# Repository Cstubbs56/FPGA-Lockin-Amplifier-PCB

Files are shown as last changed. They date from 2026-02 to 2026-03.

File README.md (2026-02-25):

# FPGA-Lockin-Amplifier-PCB
## Purpose
This PCB acts as both DAQ and a lock in amplifier for the Waterloo Rocketry 2026 fiber optic gyroscope payload. To accomplish this, it 
- Biases the fibre optic loop by outputting a sinusoid to a piezoelectric crystal via a DAC with fibre optic wrapped around the PZT.
- Reads the output of the interferometer through a photodiode into a transimpedance amplifier and ADC.
- Calculates I and Q components then exports to an SD card going through the microcontroller.

## Power Electronics
The PCB needs 24V, 5V, 3.3V, 2.5V, and 1.2V. The 24V is used for biasing the piezoelectric crystal, and goes through a 0-20V output 16 bit DAC. 5V and 3.3V are used for the analog and digital circuitry, while the 2.5V and 1.2V are solely for powering the FPGA.

## Analog Electronics
As mentioned, there is an ADC reading a transimpedance amplifier. The transimpedance amplifier was sized based on an estimated maxium output power from the interferometer of 20mW into a photodiode with an approximate response of 0.55A/W. The other side is the aforementioned DAC, which is setup to output 0-20V with a sinusoid from the FPGA.

## Logging
The FPGA being used does nt have enough extra space in the fabric to interact with a filesystem and therefore the FPGA sends results to the microcontroller to be held in RAM before outputting to the SD card. There is a piece of flash memory connected to the FPGA, but this is used for configuration.

## FPGA
Since the FPGA's non-volatile configuration memory can only be written to once, the FPGA is used with volatile configuration. This means it must configure itself each time it powers on. It uses SPI for configuration, which is hooked up to both a flash ROM and a SPI header that can be used for programming the memory from a computer.  

## Laser
The laser on the PCB is a 200mW optical power infrared laser. It draws typically around 300mA in operation.

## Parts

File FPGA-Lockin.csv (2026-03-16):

Id | Designator | Footprint | Quantity | Designation | Supplier and ref
1 | U3,U6 | SOT-563 | 2 | TLV62568ADRL
2 | R27,R26,R24 | R_0805_2012Metric_Pad1.20x1.40mm_HandSolder | 3 | 100kR
3 | L3,L2 | L_1206_3216Metric_Pad1.22x1.90mm_HandSolder | 2 | 1uH
4 | C5,C11 | C_0805_2012Metric_Pad1.18x1.45mm_HandSolder | 2 | 22uF
5 | C4,C34,C9 | C_0805_2012Metric_Pad1.18x1.45mm_HandSolder | 3 | 4.7uF
6 | C29,C12,C23,C35,C41 | C_0805_2012Metric_Pad1.18x1.45mm_HandSolder | 5 | 2.2uF
7 | C18,C17,C28,C36,C45,C40,C15,C42,C8,C38,C19,C24,C39,C37,C25 | C_0805_2012Metric_Pad1.18x1.45mm_HandSolder | 15 | 0.1uF
8 | TP11 | TestPoint_Pad_D1.0mm | 1 | SS1_an
9 | D5 | TO-5-3 | 1 | D_Photo
10 | TP7 | TestPoint_Pad_D1.0mm | 1 | MISO_an
11 | C31,C30 | C_0805_2012Metric_Pad1.18x1.45mm_HandSolder | 2 | 10pF
12 | R14,R13,R25,R22,R17,R16,R15,R20,R18,R21,R19 | R_0805_2012Metric_Pad1.20x1.40mm_HandSolder | 11 | 10kR
13 | R23 | R_0805_2012Metric_Pad1.20x1.40mm_HandSolder | 1 | 453kR
14 | TP4 | TestPoint_Pad_1.5x1.5mm | 1 | 2V5
15 | C21 | CP_EIA-7132-20_AVX-U_HandSolder | 1 | 120uF
16 | TP6 | TestPoint_Pad_1.5x1.5mm | 1 | 24V
17 | TP9,TP8 | TestPoint_Pad_D1.0mm | 2 | MOSI_an
18 | U7 | LQFP-64_10x10mm_P0.5mm | 1 | STM32F405RGTx
19 | J6 | PinSocket_2x07_P1.27mm_Vertical_SMD | 1 | Conn_02x07_Odd_Even
20 | U11 | SOIC-8_3.9x4.9mm_P1.27mm | 1 | MCP1501-30xSN
21 | C26 | C_0805_2012Metric_Pad1.18x1.45mm_HandSolder | 1 | 10 nF
22 | R9 | R_0805_2012Metric_Pad1.20x1.40mm_HandSolder | 1 | 1MR
23 | U4 | SOT-23-5 | 1 | SPX3819M5-L-2-5
24 | U8 | SOT-23-5_HandSoldering | 1 | SPX3819M5-L-3-3
25 | R10 | R_0805_2012Metric_Pad1.20x1.40mm_HandSolder | 1 | 249kR
26 | D1 | DIO_RB051MM_ROM | 1 | D_Schottky
27 | C7 | C_1210_3225Metric_Pad1.33x2.70mm_HandSolder | 1 | 180uF
28 | C27 | C_1210_3225Metric_Pad1.33x2.70mm_HandSolder | 1 | 0.1uF
29 | C43,C10,C22,C1,C3,C14 | C_0805_2012Metric_Pad1.18x1.45mm_HandSolder | 6 | 1uF
30 | TP5 | TestPoint_Pad_1.5x1.5mm | 1 | 1V2
31 | Y1 | Crystal_SMD_Abracon_ABM8G-4Pin_3.2x2.5mm | 1 | ABM8G
32 | U13 | RU-16_ADI | 1 | AD5761RBRUZ-RL7
33 | U12 | TSSOP20_ST_MCH | 1 | MCP3561R-E/ST
34 | R11 | R_0805_2012Metric_Pad1.20x1.40mm_HandSolder | 1 | 13.3kR
35 | C13 | C_1210_3225Metric_Pad1.33x2.70mm_HandSolder | 1 | 4.7uF
36 | U1 | QFN-48-1EP_7x7mm_P0.5mm_EP5.6x5.6mm | 1 | ICE40UP5K-SG48ITR
37 | TP10 | TestPoint_Pad_D1.0mm | 1 | SS0_an
38 | TP1 | TestPoint_Pad_1.5x1.5mm | 1 | 5v
39 | TP2 | TestPoint_Pad_1.5x1.5mm | 1 | 3V3
40 | U5 | SOT-23-5 | 1 | LMR64010XMF
41 | R7,R8 | R_0805_2012Metric_Pad1.20x1.40mm_HandSolder | 2 | 10R
42 | C2,C20 | C_0805_2012Metric_Pad1.18x1.45mm_HandSolder | 2 | 10nF
43 | J7 | PinSocket_1x02_P2.54mm_Vertical | 1 | Conn_01x02_Pin
44 | U14 | SOT25_DIO | 1 | AP22802AW5-7
45 | TP3 | TestPoint_Pad_1.5x1.5mm | 1 | 3V3A
46 | R4 | R_0805_2012Metric_Pad1.20x1.40mm_HandSolder | 1 | 700R
47 | R3,R1 | R_0805_2012Metric_Pad1.20x1.40mm_HandSolder | 2 | 500R
48 | U10,U16 | SOT-23-5 | 2 | OPA310xDBV
49 | D3 | LED_1206_3216Metric_Pad1.42x1.75mm_HandSolder | 1 | RED
50 | D4 | LED_1206_3216Metric_Pad1.42x1.75mm_HandSolder | 1 | GREEN
51 | TP13 | TestPoint_Pad_D1.0mm | 1 | MISO_mem
52 | U9 | SOIC-8_5.3x5.3mm_P1.27mm | 1 | W25Q32JVSS
53 | J4 | 691137710002 | 1 | PZT
54 | TP12 | TestPoint_Pad_D1.0mm | 1 | MOSI_mem
55 | TP14 | TestPoint_Pad_D1.0mm | 1 | SS0_mem
56 | C33,C32,C44 | C_0805_2012Metric_Pad1.18x1.45mm_HandSolder | 3 | 10uF
57 | R5 | R_0805_2012Metric_Pad1.20x1.40mm_HandSolder | 1 | 24kR
58 | R6 | R_0805_2012Metric_Pad1.20x1.40mm_HandSolder | 1 | 240R
59 | TPS1_m1 | TestPoint_Pad_D1.0mm | 1 | SS1_mem
60 | F1 | Fuse_1812_4532Metric_Pad1.30x3.40mm_HandSolder | 1 | 0ZCG0075FF2C
61 | FL1 | BEADC1608X95N | 1 | BLM18PG121SN1D
62 | J3 | 691137710002 | 1 | Laser
63 | R12 | R_0805_2012Metric_Pad1.20x1.40mm_HandSolder | 1 | 25mR
64 | D2 | LED_1206_3216Metric_Pad1.42x1.75mm_HandSolder | 1 | BLUE
65 | J5 | microSD_Molex_WM6698CT-ND | 1 | Micro_SD_Card
66 | L1 | IND_BOURNS_CC453232 | 1 | CC453232-120KL
67 | U2 | SOT-23-5_HandSoldering | 1 | INA180
68 | J1 | PinHeader_1x04_P2.54mm_Vertical | 1 | SPI Header
69 | U15 | SOIC-8_3.9x4.9mm_P1.27mm | 1 | MCP2562
70 | R2 | R_0805_2012Metric_Pad1.20x1.40mm_HandSolder | 1 | 330R
71 | J2 | connector_Harwin_G125-MH104M4-04AD000P | 1 | G125-MH104M4-04AD000P
72 | TP15 | TestPoint_Pad_D1.0mm | 1 | SCLK_mem
73 | C16 | C_0805_2012Metric_Pad1.18x1.45mm_HandSolder | 1 | 33nF

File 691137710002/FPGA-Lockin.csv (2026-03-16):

Id | Designator | Footprint | Quantity | Designation | Supplier and ref
1 | C29,C12,C23,C35,C41 | C_0805_2012Metric_Pad1.18x1.45mm_HandSolder | 5 | 2.2uF
2 | U14 | SOT-363_SC-70-6 | 1 | MIC94090YC6
3 | C18,C17,C43,C28,C36,C40,C15,C42,C8,C38,C19,C24,C39,C37,C25 | C_0805_2012Metric_Pad1.18x1.45mm_HandSolder | 15 | 0.1uF
4 | TP11 | TestPoint_Pad_D1.0mm | 1 | SS1_an
5 | D5 | TO-5-3 | 1 | D_Photo
6 | TP7 | TestPoint_Pad_D1.0mm | 1 | MISO_an
7 | C31,C30 | C_0805_2012Metric_Pad1.18x1.45mm_HandSolder | 2 | 10pF
8 | R14,R13,R22,R17,R16,R15,R20,R18,R21,R19 | R_0805_2012Metric_Pad1.20x1.40mm_HandSolder | 10 | 10kR
9 | R23 | R_0805_2012Metric_Pad1.20x1.40mm_HandSolder | 1 | 453kR
10 | TP4 | TestPoint_Pad_1.5x1.5mm | 1 | 2V5
11 | TP6 | TestPoint_Pad_1.5x1.5mm | 1 | 24V
12 | TP9,TP8 | TestPoint_Pad_D1.0mm | 2 | MOSI_an
13 | U7 | LQFP-64_10x10mm_P0.5mm | 1 | STM32F405RGTx
14 | C34,C9 | C_0805_2012Metric_Pad1.18x1.45mm_HandSolder | 2 | 4.7uF
15 | L2 | L_1206_3216Metric_Pad1.22x1.90mm_HandSolder | 1 | 1uH
16 | J6 | PinSocket_2x07_P1.27mm_Vertical_SMD | 1 | Conn_02x07_Odd_Even
17 | U11 | SOIC-8_3.9x4.9mm_P1.27mm | 1 | MCP1501-30xSN
18 | C11 | C_0805_2012Metric_Pad1.18x1.45mm_HandSolder | 1 | 22uF
19 | C26 | C_0805_2012Metric_Pad1.18x1.45mm_HandSolder | 1 | 10 nF
20 | R9 | R_0805_2012Metric_Pad1.20x1.40mm_HandSolder | 1 | 1MR
21 | U4 | SOT-23-5 | 1 | SPX3819M5-L-2-5
22 | U8 | SOT-23-5_HandSoldering | 1 | SPX3819M5-L-3-3
23 | R10 | R_0805_2012Metric_Pad1.20x1.40mm_HandSolder | 1 | 249kR
24 | D1 | DIO_RB051MM_ROM | 1 | D_Schottky
25 | C7 | C_1210_3225Metric_Pad1.33x2.70mm_HandSolder | 1 | 180uF
26 | C27 | C_1210_3225Metric_Pad1.33x2.70mm_HandSolder | 1 | 0.1uF
27 | TP5 | TestPoint_Pad_1.5x1.5mm | 1 | 1V2
28 | Y1 | Crystal_SMD_Abracon_ABM8G-4Pin_3.2x2.5mm | 1 | ABM8G
29 | U13 | RU-16_ADI | 1 | AD5761RBRUZ-RL7
30 | U12 | TSSOP20_ST_MCH | 1 | MCP3561R-E/ST
31 | R11 | R_0805_2012Metric_Pad1.20x1.40mm_HandSolder | 1 | 13.3kR
32 | C13 | C_1210_3225Metric_Pad1.33x2.70mm_HandSolder | 1 | 4.7uF
33 | C10,C22,C1,C3,C6,C4,C14 | C_0805_2012Metric_Pad1.18x1.45mm_HandSolder | 7 | 1uF
34 | U1 | QFN-48-1EP_7x7mm_P0.5mm_EP5.6x5.6mm | 1 | ICE40UP5K-SG48ITR
35 | TP10 | TestPoint_Pad_D1.0mm | 1 | SS0_an
36 | TP1 | TestPoint_Pad_1.5x1.5mm | 1 | 5v
37 | TP2 | TestPoint_Pad_1.5x1.5mm | 1 | 3V3
38 | R24 | R_0805_2012Metric_Pad1.20x1.40mm_HandSolder | 1 | 100kR
39 | U5 | SOT-23-5 | 1 | LMR64010XMF
40 | R7,R8 | R_0805_2012Metric_Pad1.20x1.40mm_HandSolder | 2 | 10R
41 | C2,C5,C20 | C_0805_2012Metric_Pad1.18x1.45mm_HandSolder | 3 | 10nF
42 | J7 | PinSocket_1x02_P2.54mm_Vertical | 1 | Conn_01x02_Pin
43 | U6 | SOT-563 | 1 | TLV62568ADRL
44 | TP3 | TestPoint_Pad_1.5x1.5mm | 1 | 3V3A
45 | U3 | SOT-23-5 | 1 | SPX3819M5-L-1-2
46 | R4 | R_0805_2012Metric_Pad1.20x1.40mm_HandSolder | 1 | 700R
47 | R3,R1 | R_0805_2012Metric_Pad1.20x1.40mm_HandSolder | 2 | 500R
48 | U10,U16 | SOT-23-5 | 2 | OPA310xDBV
49 | D3 | LED_1206_3216Metric_Pad1.42x1.75mm_HandSolder | 1 | RED
50 | D4 | LED_1206_3216Metric_Pad1.42x1.75mm_HandSolder | 1 | GREEN
51 | TP13 | TestPoint_Pad_D1.0mm | 1 | MISO_mem
52 | U9 | SOIC-8_5.3x5.3mm_P1.27mm | 1 | W25Q32JVSS
53 | J4 | 691137710002 | 1 | PZT
54 | TP12 | TestPoint_Pad_D1.0mm | 1 | MOSI_mem
55 | TP14 | TestPoint_Pad_D1.0mm | 1 | SS0_mem
56 | C33,C32,C44 | C_0805_2012Metric_Pad1.18x1.45mm_HandSolder | 3 | 10uF
57 | R5 | R_0805_2012Metric_Pad1.20x1.40mm_HandSolder | 1 | 24kR
58 | R6 | R_0805_2012Metric_Pad1.20x1.40mm_HandSolder | 1 | 240R
59 | TPS1_m1 | TestPoint_Pad_D1.0mm | 1 | SS1_mem
60 | F1 | Fuse_1812_4532Metric_Pad1.30x3.40mm_HandSolder | 1 | 0ZCG0075FF2C
61 | FL1 | BEADC1608X95N | 1 | BLM18PG121SN1D
62 | J3 | 691137710002 | 1 | Laser
63 | R12 | R_0805_2012Metric_Pad1.20x1.40mm_HandSolder | 1 | 25mR
64 | D2 | LED_1206_3216Metric_Pad1.42x1.75mm_HandSolder | 1 | BLUE
65 | J5 | microSD_Molex_WM6698CT-ND | 1 | Micro_SD_Card
66 | L1 | IND_BOURNS_CC453232 | 1 | CC453232-120KL
67 | U2 | SOT-23-5_HandSoldering | 1 | INA180
68 | J1 | PinHeader_1x04_P2.54mm_Vertical | 1 | SPI Header
69 | U15 | SOIC-8_3.9x4.9mm_P1.27mm | 1 | MCP2562
70 | R2 | R_0805_2012Metric_Pad1.20x1.40mm_HandSolder | 1 | 330R
71 | J2 | connector_Harwin_G125-MH104M4-04AD000P | 1 | G125-MH104M4-04AD000P
72 | TP15 | TestPoint_Pad_D1.0mm | 1 | SCLK_mem
73 | C16 | C_0805_2012Metric_Pad1.18x1.45mm_HandSolder | 1 | 33nF

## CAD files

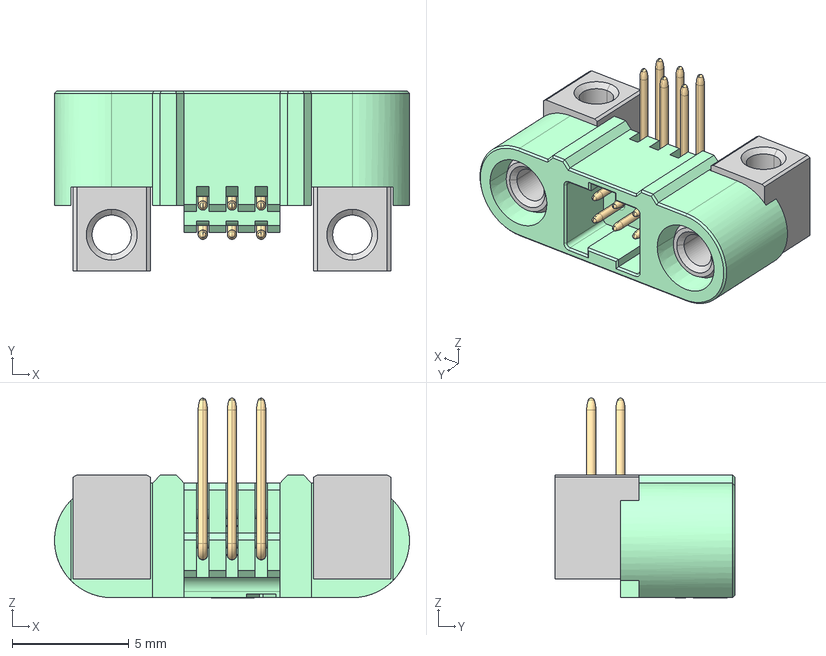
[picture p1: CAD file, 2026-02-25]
kicad-footprints/3d/g125-mh10605m4_asm.stp
15.2 x 7.70 x 8.55 mm
G125-3270696
G125-4640000 x 2
G125-1060005_BENT x 3
G125-1070005_BENT x 3

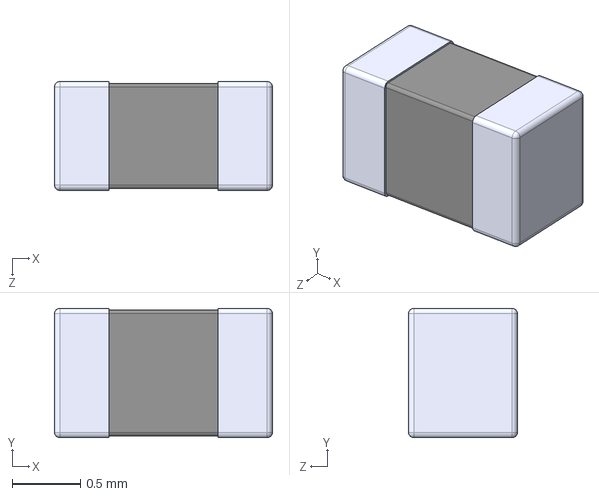
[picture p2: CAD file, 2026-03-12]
BLM18PG121SN1D/BLM18PG121SN1D.step
1.60 x 0.95 x 0.8 mm

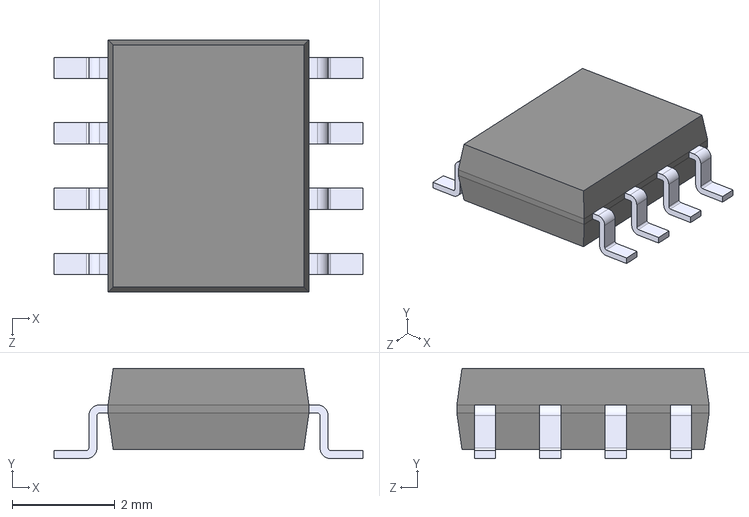
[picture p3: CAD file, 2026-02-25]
MCP2562_E_SN/MCP2562-E_SN.step
6.00 x 1.75 x 4.90 mm

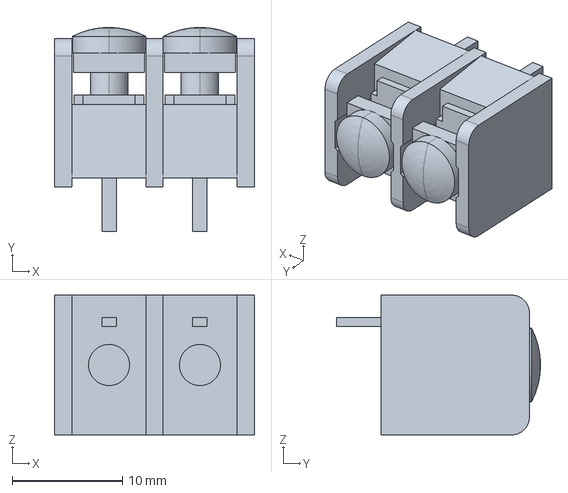
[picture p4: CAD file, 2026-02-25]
kicad-footprints/3d/4DB-P108-02.stp
18.2 x 18.5 x 12.7 mm

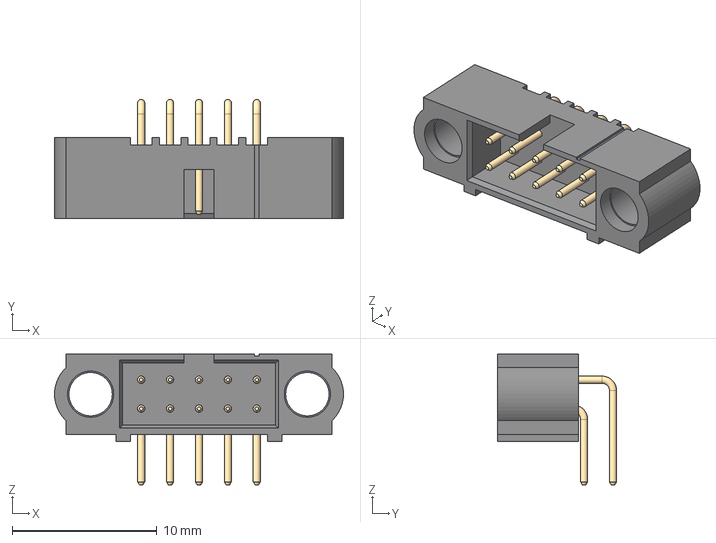
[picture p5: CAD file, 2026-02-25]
kicad-footprints/3d/Harwin_-_M80-5401042.step
20.0 x 8.25 x 9.06 mm

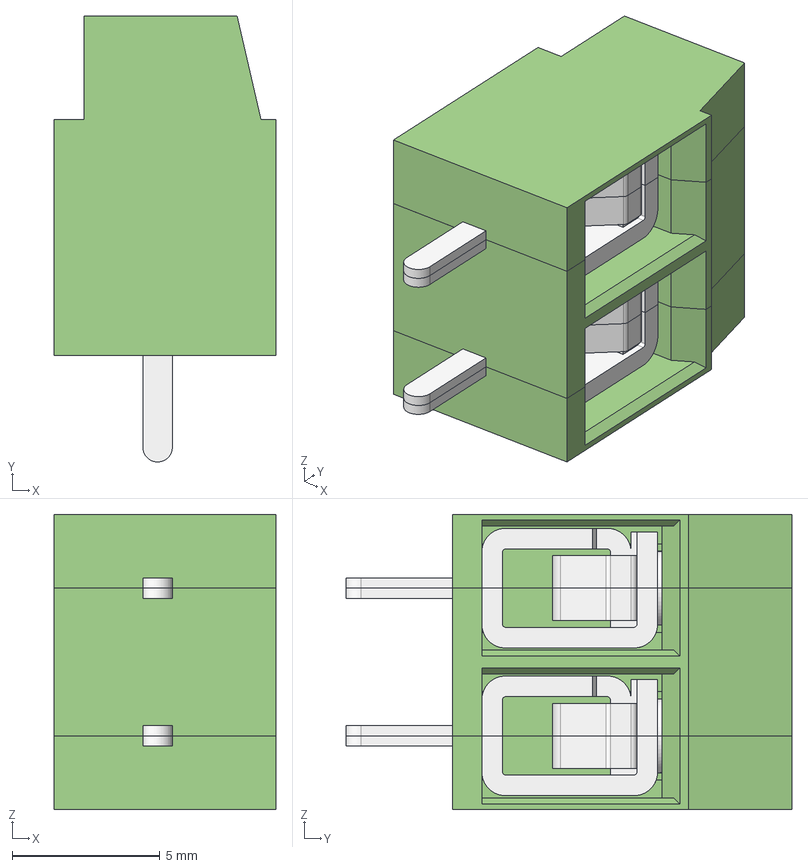
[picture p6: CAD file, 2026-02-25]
691137710002/691137710002.step
7.50 x 15.1 x 10.0 mm
MRT12P5_SX
MRT12P5_CNT
MRT12P5_DX

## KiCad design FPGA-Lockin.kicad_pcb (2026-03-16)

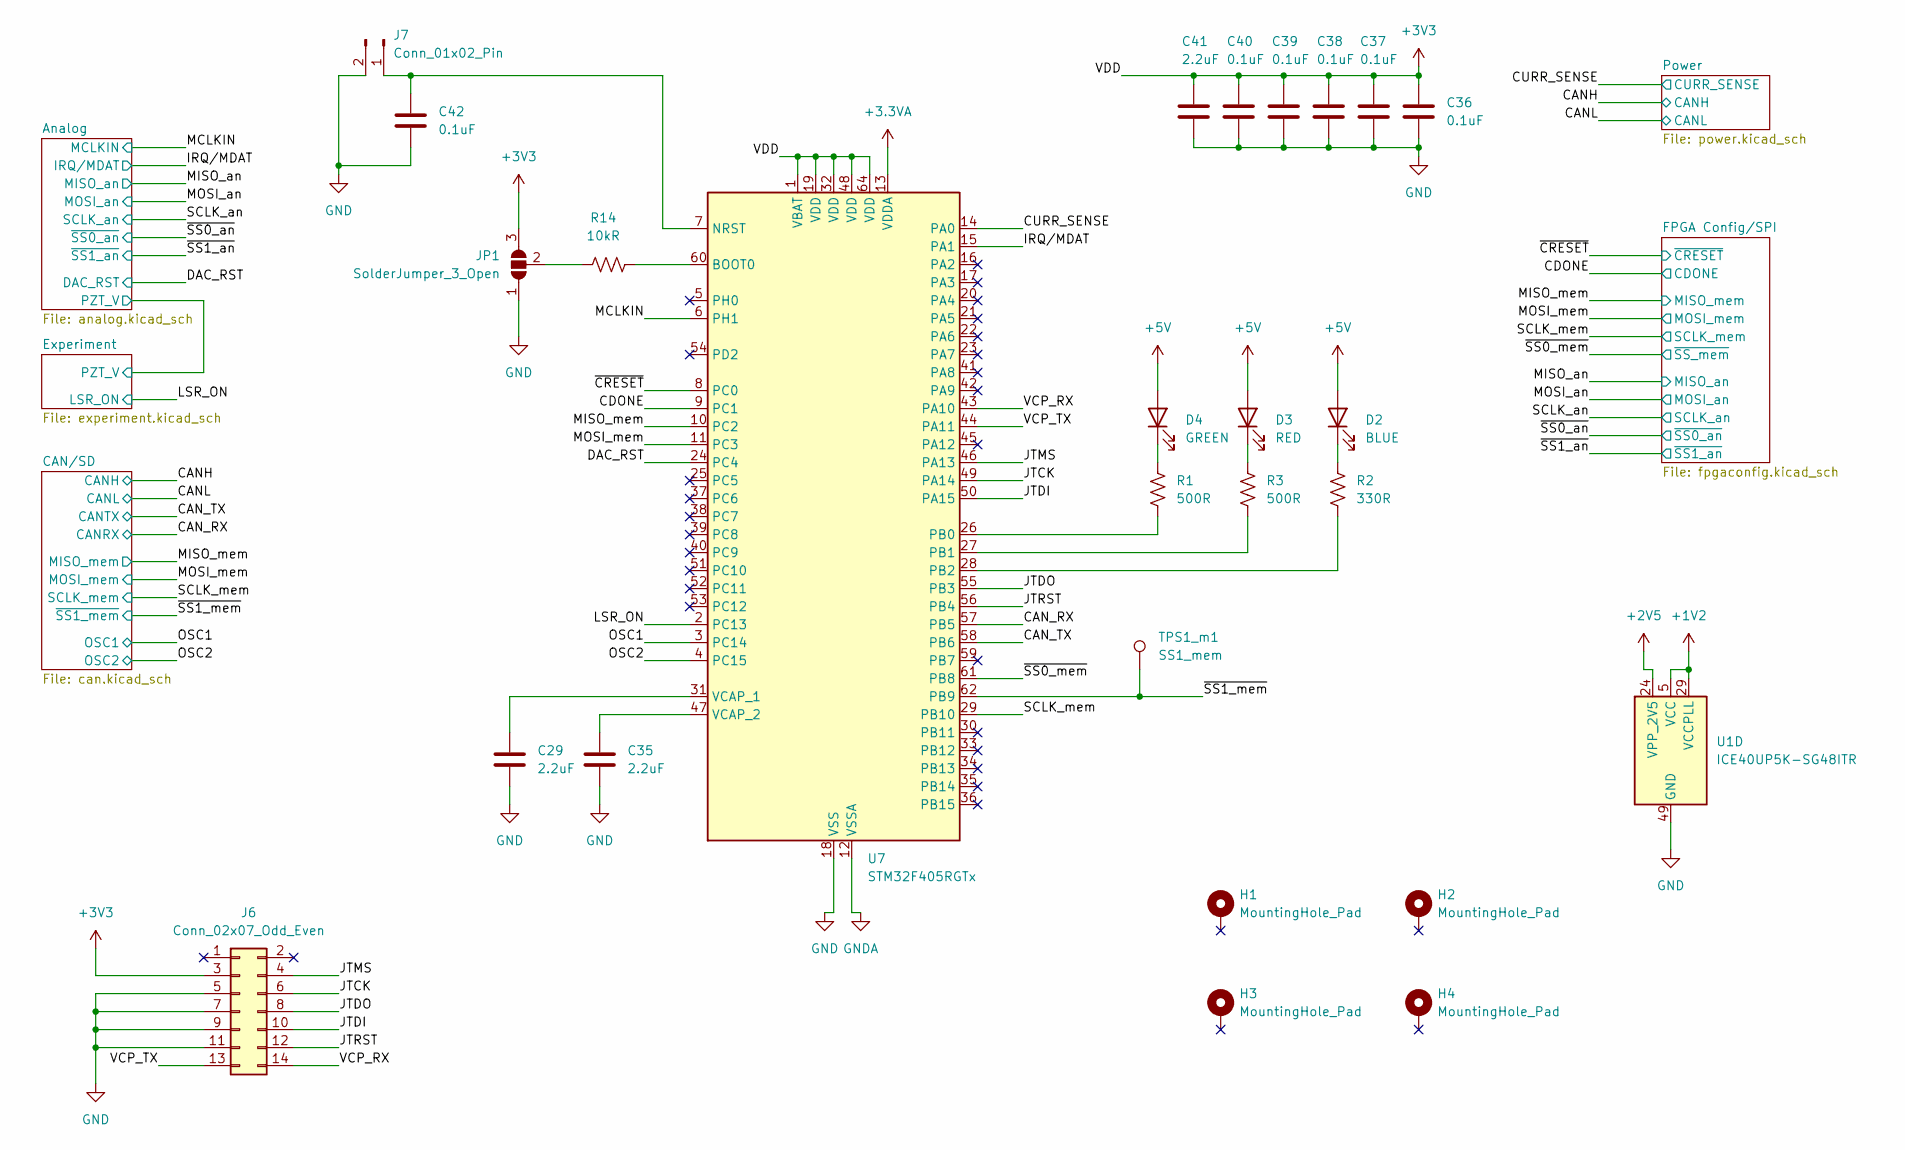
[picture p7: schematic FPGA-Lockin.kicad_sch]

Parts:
C29, C35, C41: 2.2uF; C_0805_2012Metric_Pad1.18x1.45mm_HandSolder
C36, C37, C38, C39, C40, C42: 0.1uF; C_0805_2012Metric_Pad1.18x1.45mm_HandSolder
D2: BLUE; LED_1206_3216Metric_Pad1.42x1.75mm_HandSolder
D3: RED; LED_1206_3216Metric_Pad1.42x1.75mm_HandSolder
D4: GREEN; LED_1206_3216Metric_Pad1.42x1.75mm_HandSolder
H1, H2, H3, H4: MountingHole_Pad; MountingHole_3.2mm_M3_Pad
J6: Conn_02x07_Odd_Even; PinSocket_2x07_P1.27mm_Vertical_SMD
J7: Conn_01x02_Pin; PinSocket_1x02_P2.54mm_Vertical
JP1: SolderJumper_3_Open; SolderJumper-3_P1.3mm_Open_RoundedPad1.0x1.5mm
R1, R3: 500R; R_0805_2012Metric_Pad1.20x1.40mm_HandSolder
R2: 330R; R_0805_2012Metric_Pad1.20x1.40mm_HandSolder
R14: 10kR; R_0805_2012Metric_Pad1.20x1.40mm_HandSolder
TPS1_m1: SS1_mem; TestPoint_Pad_D1.0mm
U1: ICE40UP5K-SG48ITR; QFN-48-1EP_7x7mm_P0.5mm_EP5.6x5.6mm
U7: STM32F405RGTx; LQFP-64_10x10mm_P0.5mm

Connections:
+1V2: U1.5 (VCC), U1.29 (VCCPLL), U1.30 (VCC); also elsewhere on the board
+2V5: U1.24 (VPP_2V5); also elsewhere on the board
+3.3VA: U7.13 (VDDA); also elsewhere on the board
+3V3: C36.1, C37.1, C38.1, C39.1, C40.1, C41.1, J6.3, JP1.3 (B), U7.1 (VBAT), U7.19 (VDD), U7.32 (VDD), U7.48 (VDD), U7.64 (VDD); also elsewhere on the board
+5V: D2.2 (A), D3.2 (A), D4.2 (A); also elsewhere on the board
/CAN_RX: U7.57 (PB5); also elsewhere on the board
/CAN_TX: U7.58 (PB6); also elsewhere on the board
/CDONE: U7.9 (PC1); also elsewhere on the board
/CURR_SENSE: U7.14 (PA0); also elsewhere on the board
/DAC_RST: U7.24 (PC4); also elsewhere on the board
/IRQ/MDAT: U7.15 (PA1); also elsewhere on the board
/JTCK: J6.6, U7.49 (PA14)
/JTDI: J6.10, U7.50 (PA15)
/JTDO: J6.8, U7.55 (PB3)
/JTMS: J6.4, U7.46 (PA13)
/JTRST: J6.12, U7.56 (PB4)
/LSR_ON: U7.2 (PC13); also elsewhere on the board
/MCLKIN: U7.6 (PH1); also elsewhere on the board
/MISO_mem: U7.10 (PC2); also elsewhere on the board
/MOSI_mem: U7.11 (PC3); also elsewhere on the board
/OSC1: U7.3 (PC14); also elsewhere on the board
/OSC2: U7.4 (PC15); also elsewhere on the board
/SCLK_mem: U7.29 (PB10); also elsewhere on the board
/VCP_RX: J6.14, U7.43 (PA10)
/VCP_TX: J6.13, U7.44 (PA11)
/~CRESET: U7.8 (PC0); also elsewhere on the board
/~SS0_mem: U7.61 (PB8); also elsewhere on the board
/~SS1_mem: TPS1_m1.1, U7.62 (PB9); also elsewhere on the board
GND: C29.2, C35.2, C36.2, C37.2, C38.2, C39.2, C40.2, C41.2, C42.2, J6.5, J6.7, J6.9, J6.11, J7.2, JP1.1 (A), U1.49 (GND), U7.18 (VSS), U7.63 (VSS); also elsewhere on the board
GNDA: U7.12 (VSSA); also elsewhere on the board
unnamed: D2.1 (K), R2.1
unnamed: D3.1 (K), R3.1
unnamed: D4.1 (K), R1.1
unnamed: C42.1, J7.1, U7.7 (NRST)
unnamed: JP1.2 (C), R14.2
unnamed: R14.1, U7.60 (BOOT0)
unnamed: R1.2, U7.26 (PB0)
unnamed: R3.2, U7.27 (PB1)
unnamed: R2.2, U7.28 (PB2)
unnamed: C29.1, U7.31 (VCAP_1)
unnamed: C35.1, U7.47 (VCAP_2)

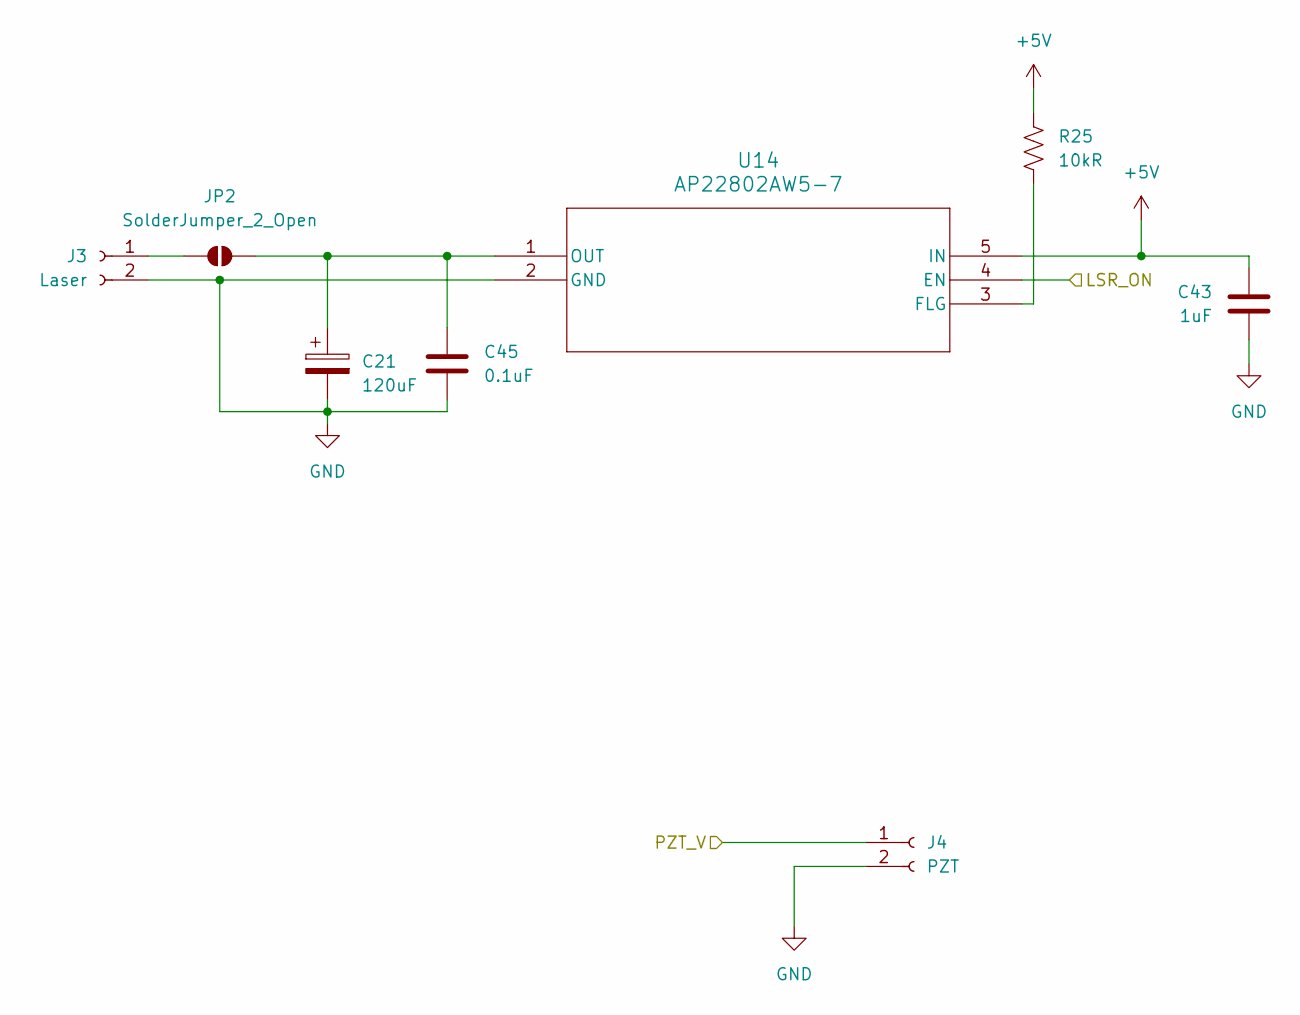
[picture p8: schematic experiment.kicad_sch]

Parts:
C21: 120uF; CP_EIA-7132-20_AVX-U_HandSolder
C43: 1uF; C_0805_2012Metric_Pad1.18x1.45mm_HandSolder
C45: 0.1uF; C_0805_2012Metric_Pad1.18x1.45mm_HandSolder
J3: Laser; 691137710002
J4: PZT; 691137710002
JP2: SolderJumper_2_Open; SolderJumper-2_P1.3mm_Open_RoundedPad1.0x1.5mm
R25: 10kR; R_0805_2012Metric_Pad1.20x1.40mm_HandSolder
U14: AP22802AW5-7; SOT25_DIO

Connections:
+5V: C43.2, R25.1, U14.5 (IN); also elsewhere on the board
/Analog/PZT_V: J4.1; also elsewhere on the board
/LSR_ON: U14.4 (EN); also elsewhere on the board
GND: C21.2, C43.1, C45.2, J3.2, J4.2, U14.2 (GND); also elsewhere on the board
unnamed: J3.1, JP2.2 (B)
unnamed: C21.1, C45.1, JP2.1 (A), U14.1 (OUT)
unnamed: R25.2, U14.3 (FLG)

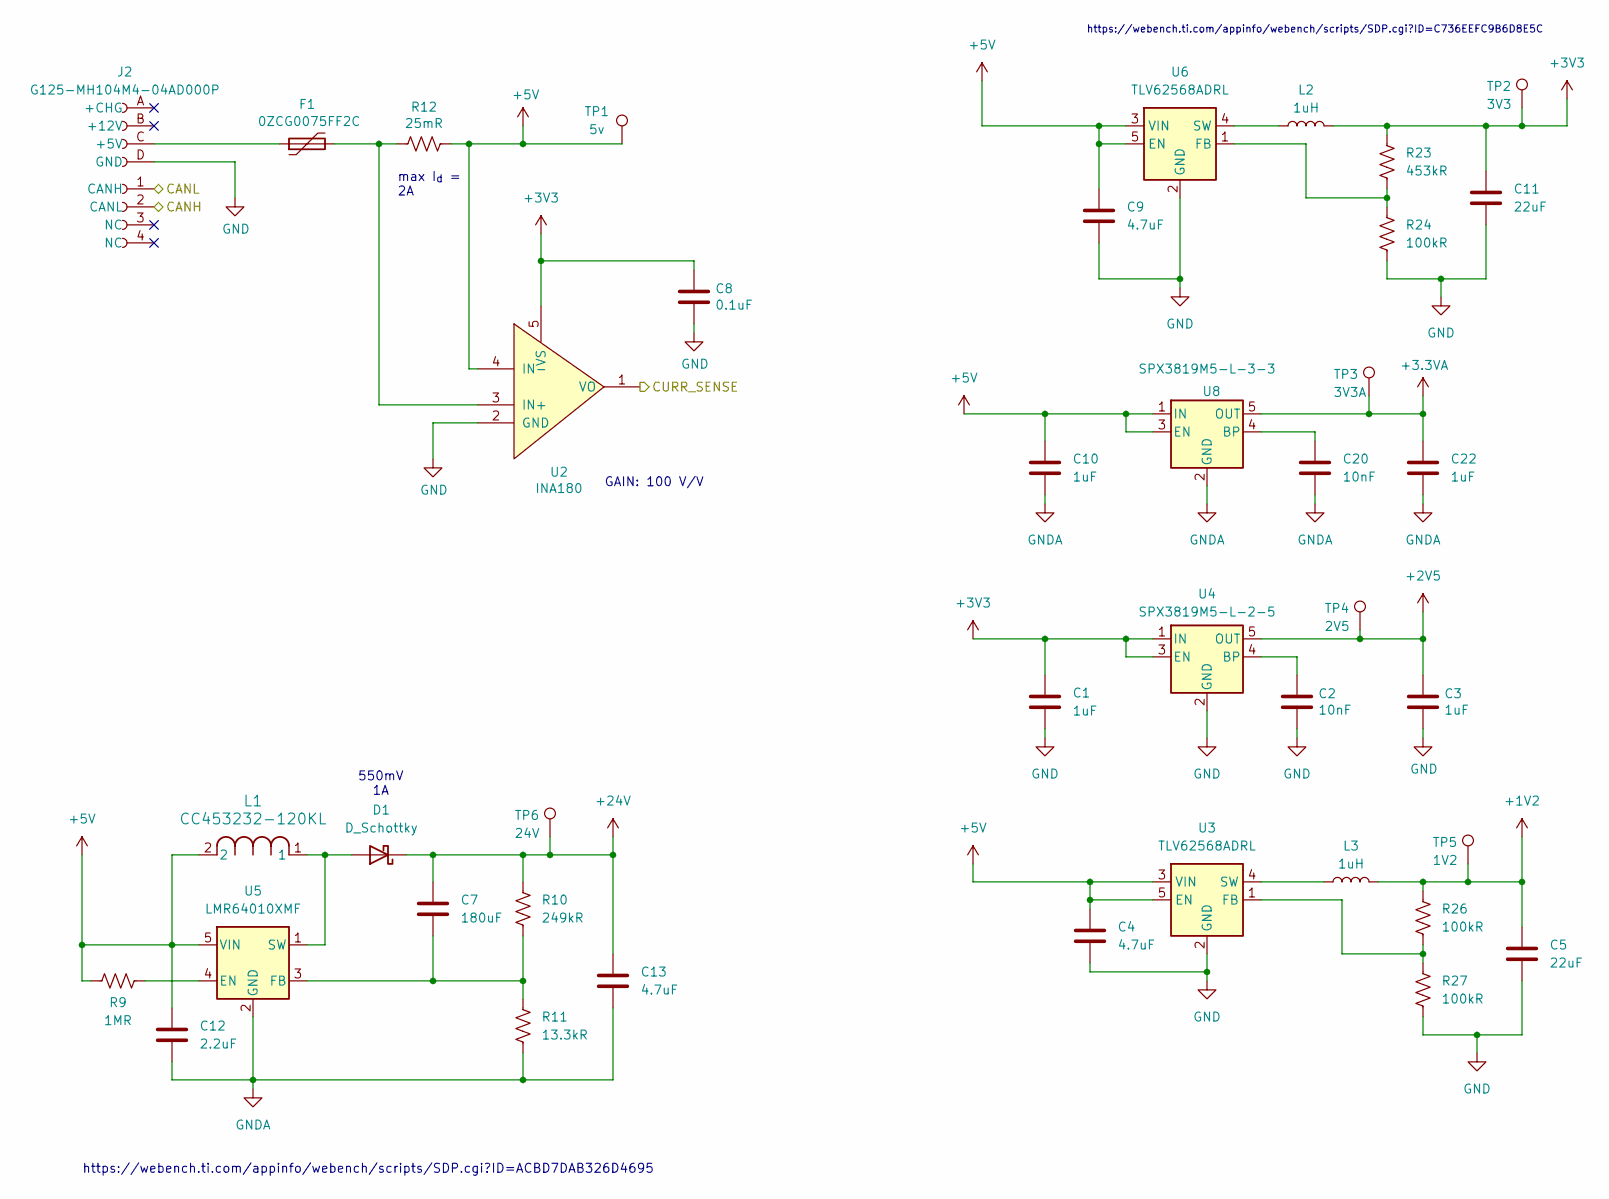
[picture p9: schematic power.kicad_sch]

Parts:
C1, C10, C22: 1uF; C_0805_2012Metric_Pad1.18x1.45mm_HandSolder
C2: 10nF; C_0805_2012Metric_Pad1.18x1.45mm_HandSolder; DigiKey 732-12169-1-ND
C3: 1uF; C_0805_2012Metric_Pad1.18x1.45mm_HandSolder; DigiKey 1276-6470-1-ND
C4, C9: 4.7uF; C_0805_2012Metric_Pad1.18x1.45mm_HandSolder
C5, C11: 22uF; C_0805_2012Metric_Pad1.18x1.45mm_HandSolder
C7: 180uF; C_1210_3225Metric_Pad1.33x2.70mm_HandSolder
C8: 0.1uF; C_0805_2012Metric_Pad1.18x1.45mm_HandSolder; DigiKey 311-1858-1-ND
C12: 2.2uF; C_0805_2012Metric_Pad1.18x1.45mm_HandSolder
C13: 4.7uF; C_1210_3225Metric_Pad1.33x2.70mm_HandSolder
C20: 10nF; C_0805_2012Metric_Pad1.18x1.45mm_HandSolder
D1: D_Schottky; DIO_RB051MM_ROM
F1: 0ZCG0075FF2C; Fuse_1812_4532Metric_Pad1.30x3.40mm_HandSolder; DigiKey F3732CT-ND
J2: G125-MH104M4-04AD000P; connector_Harwin_G125-MH104M4-04AD000P
L1: CC453232-120KL; IND_BOURNS_CC453232
L2, L3: 1uH; L_1206_3216Metric_Pad1.22x1.90mm_HandSolder
R9: 1MR; R_0805_2012Metric_Pad1.20x1.40mm_HandSolder
R10: 249kR; R_0805_2012Metric_Pad1.20x1.40mm_HandSolder
R11: 13.3kR; R_0805_2012Metric_Pad1.20x1.40mm_HandSolder
R12: 25mR; R_0805_2012Metric_Pad1.20x1.40mm_HandSolder; DigiKey WSLB-.20CT-ND
R23: 453kR; R_0805_2012Metric_Pad1.20x1.40mm_HandSolder
R24, R26, R27: 100kR; R_0805_2012Metric_Pad1.20x1.40mm_HandSolder
TP1: 5v; TestPoint_Pad_1.5x1.5mm
TP2: 3V3; TestPoint_Pad_1.5x1.5mm
TP3: 3V3A; TestPoint_Pad_1.5x1.5mm
TP4: 2V5; TestPoint_Pad_1.5x1.5mm
TP5: 1V2; TestPoint_Pad_1.5x1.5mm
TP6: 24V; TestPoint_Pad_1.5x1.5mm
U2: INA180; SOT-23-5_HandSoldering; DigiKey 296-INA180A3QDBVRQ1CT-ND
U3, U6: TLV62568ADRL; SOT-563
U4: SPX3819M5-L-2-5; SOT-23-5
U5: LMR64010XMF; SOT-23-5
U8: SPX3819M5-L-3-3; SOT-23-5_HandSoldering; DigiKey 1016-1873-1-ND

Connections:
+1V2: C5.1, L3.2, R26.1, TP5.1; also elsewhere on the board
+2V5: C3.1, TP4.1, U4.5 (OUT); also elsewhere on the board
+3.3VA: C22.1, TP3.1, U8.5 (OUT); also elsewhere on the board
+3V3: C1.1, C8.1, C11.1, L2.2, R23.1, TP2.1, U2.5 (VS), U4.1 (IN), U4.3 (EN); also elsewhere on the board
+5V: C4.1, C9.1, C10.1, C12.1, L1.2, R9.2, R12.1, TP1.1, U2.4 (IN-), U3.3 (VIN), U3.5 (EN), U5.5 (VIN), U6.3 (VIN), U6.5 (EN), U8.1 (IN), U8.3 (EN); also elsewhere on the board
+24V: C7.1, C13.1, D1.1 (K), R10.1, TP6.1; also elsewhere on the board
/CANH: J2.2 (CANL); also elsewhere on the board
/CANL: J2.1 (CANH); also elsewhere on the board
/CURR_SENSE: U2.1 (VO); also elsewhere on the board
GND: C1.2, C2.2, C3.2, C4.2, C5.2, C8.2, C9.2, C11.2, J2.D (GND), R24.2, R27.2, U2.2 (GND), U3.2 (GND), U4.2 (GND), U6.2 (GND); also elsewhere on the board
GNDA: C10.2, C12.2, C13.2, C20.2, C22.2, R11.2, U5.2 (GND), U8.2 (GND); also elsewhere on the board
unnamed: D1.2 (A), L1.1, U5.1 (SW)
unnamed: F1.1, J2.C (+5V)
unnamed: F1.2, R12.2, U2.3 (IN+)
unnamed: R26.2, R27.1, U3.1 (FB)
unnamed: L3.1, U3.4 (SW)
unnamed: C2.1, U4.4 (BP)
unnamed: R9.1, U5.4 (EN)
unnamed: C7.2, R10.2, R11.1, U5.3 (FB)
unnamed: R23.2, R24.1, U6.1 (FB)
unnamed: L2.1, U6.4 (SW)
unnamed: C20.1, U8.4 (BP)

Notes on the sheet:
GAIN: 100 V/V
https://webench.ti.com/appinfo/webench/scripts/SDP.cgi?ID=C736EEFC9B6D8E5C
max I_{d} = 2A
550mV 1A
https://webench.ti.com/appinfo/webench/scripts/SDP.cgi?ID=ACBD7DAB326D4695

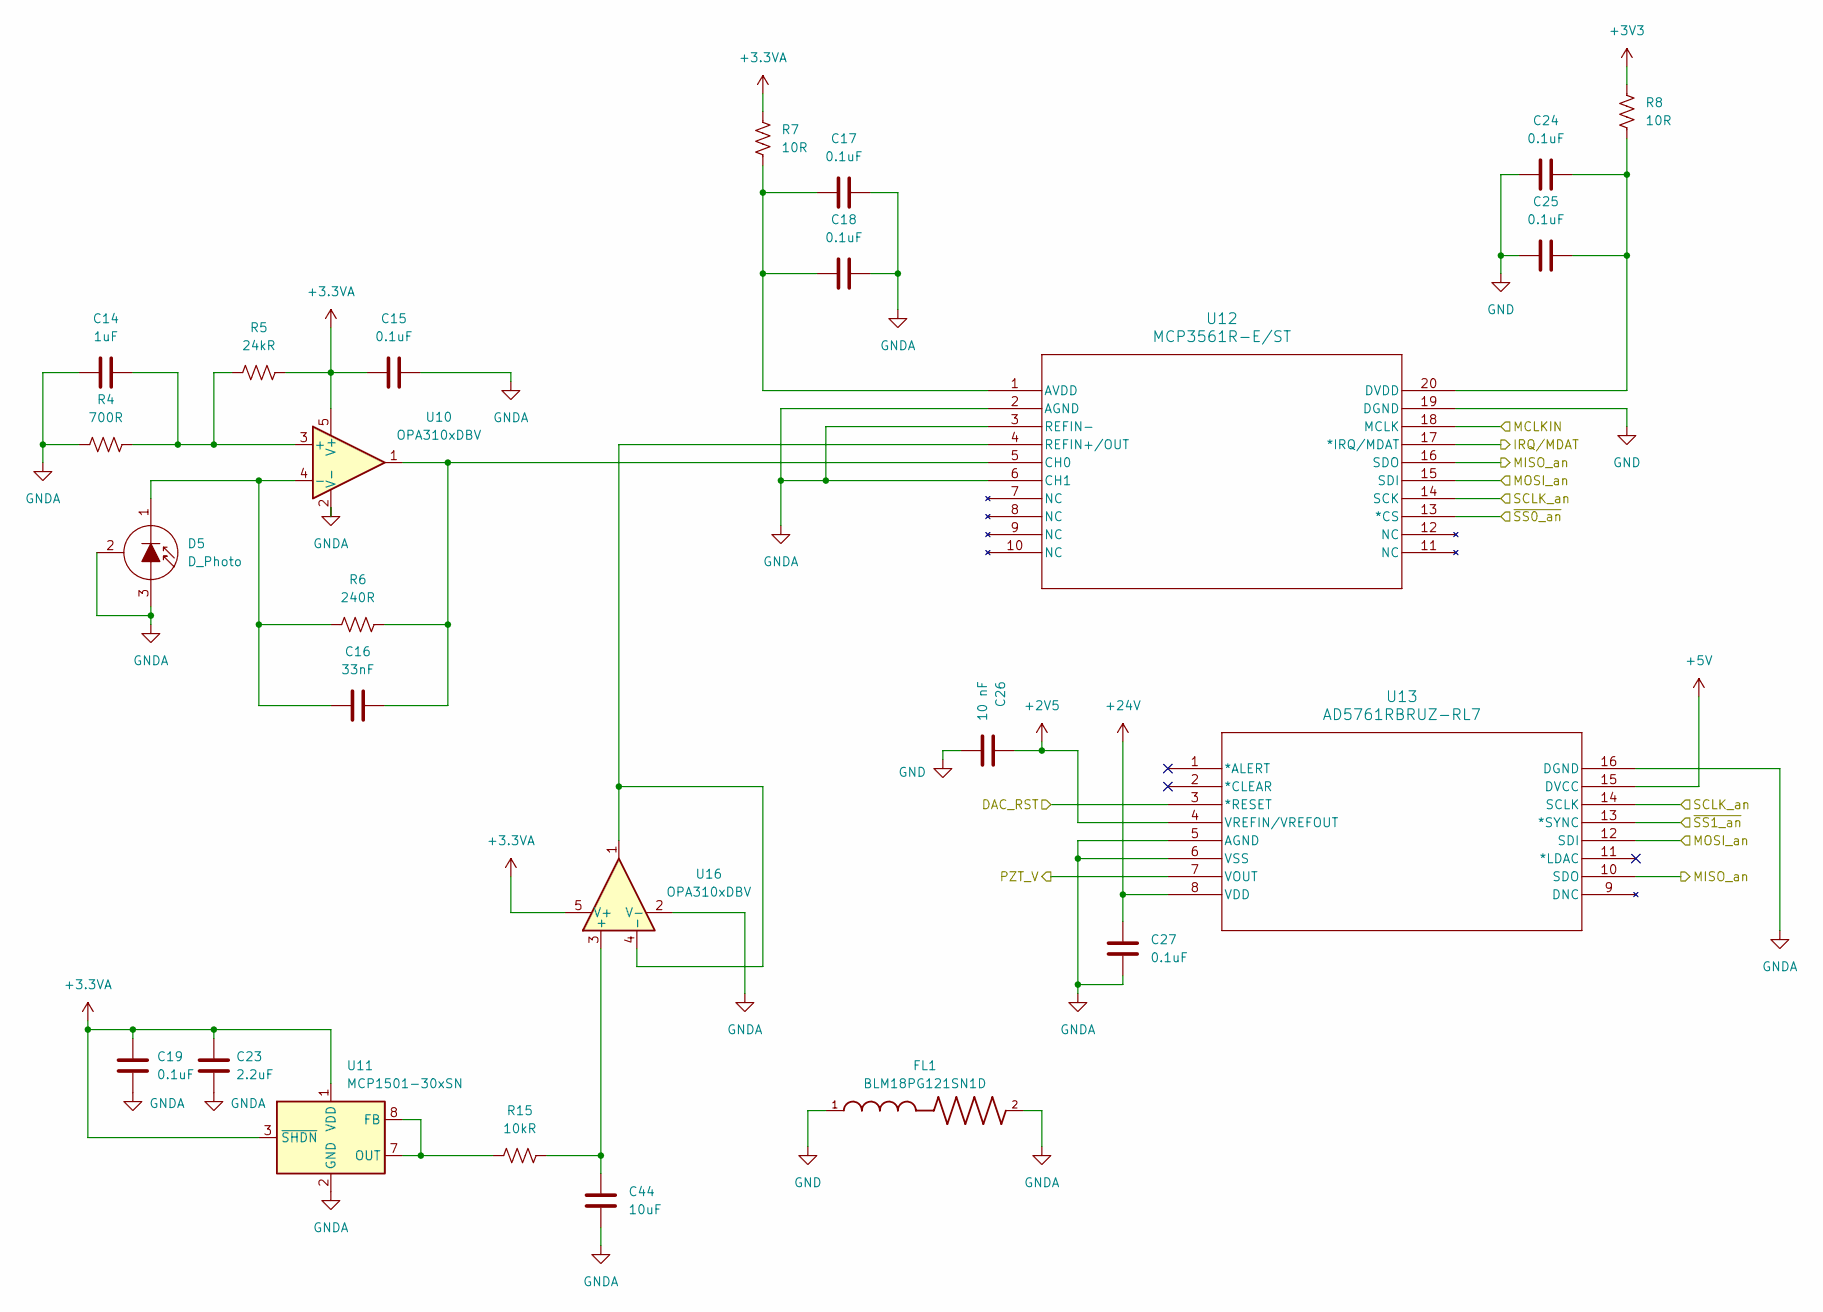
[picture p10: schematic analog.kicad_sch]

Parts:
C14: 1uF; C_0805_2012Metric_Pad1.18x1.45mm_HandSolder
C15, C17, C18, C19, C24, C25: 0.1uF; C_0805_2012Metric_Pad1.18x1.45mm_HandSolder
C16: 33nF; C_0805_2012Metric_Pad1.18x1.45mm_HandSolder
C23: 2.2uF; C_0805_2012Metric_Pad1.18x1.45mm_HandSolder
C26: 10 nF; C_0805_2012Metric_Pad1.18x1.45mm_HandSolder
C27: 0.1uF; C_1210_3225Metric_Pad1.33x2.70mm_HandSolder
C44: 10uF; C_0805_2012Metric_Pad1.18x1.45mm_HandSolder
D5: D_Photo; TO-5-3
FL1: BLM18PG121SN1D; BEADC1608X95N
R4: 700R; R_0805_2012Metric_Pad1.20x1.40mm_HandSolder
R5: 24kR; R_0805_2012Metric_Pad1.20x1.40mm_HandSolder
R6: 240R; R_0805_2012Metric_Pad1.20x1.40mm_HandSolder
R7, R8: 10R; R_0805_2012Metric_Pad1.20x1.40mm_HandSolder
R15: 10kR; R_0805_2012Metric_Pad1.20x1.40mm_HandSolder
U10, U16: OPA310xDBV; SOT-23-5
U11: MCP1501-30xSN; SOIC-8_3.9x4.9mm_P1.27mm
U12: MCP3561R-E/ST; TSSOP20_ST_MCH
U13: AD5761RBRUZ-RL7; RU-16_ADI

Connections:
+2V5: C26.1, U13.4 (VREFIN/VREFOUT); also elsewhere on the board
+3.3VA: C15.2, C19.1, C23.1, R5.2, R7.1, U10.5 (V+), U11.1 (VDD), U11.3 (~SHDN), U16.5 (V+); also elsewhere on the board
+3V3: R8.1; also elsewhere on the board
+5V: U13.15 (DVCC); also elsewhere on the board
+24V: C27.1, U13.8 (VDD); also elsewhere on the board
/Analog/PZT_V: U13.7 (VOUT); also elsewhere on the board
/DAC_RST: U13.3 (*RESET); also elsewhere on the board
/IRQ/MDAT: U12.17 (*IRQ/MDAT); also elsewhere on the board
/MCLKIN: U12.18 (MCLK); also elsewhere on the board
/MISO_an: U12.16 (SDO), U13.10 (SDO); also elsewhere on the board
/MOSI_an: U12.15 (SDI), U13.12 (SDI); also elsewhere on the board
/SCLK_an: U12.14 (SCK), U13.14 (SCLK); also elsewhere on the board
/~SS0_an: U12.13 (*CS); also elsewhere on the board
/~SS1_an: U13.13 (*SYNC); also elsewhere on the board
GND: C24.1, C25.1, C26.2, FL1.1, U12.19 (DGND); also elsewhere on the board
GNDA: C14.2, C15.1, C17.2, C18.2, C19.2, C23.2, C27.2, C44.2, D5.2 (C), D5.3 (A), FL1.2, R4.1, U10.2 (V-), U11.2 (GND), U11.4 (GND), U11.5 (GND), U11.6 (GND), U12.2 (AGND), U12.3 (REFIN-), U12.6 (CH1), U13.5 (AGND), U13.6 (VSS), U13.16 (DGND), U16.2 (V-); also elsewhere on the board
unnamed: C16.2, D5.1 (K), R6.1, U10.4 (-)
unnamed: C14.1, R4.2, R5.1, U10.3 (+)
unnamed: R15.1, U11.7 (OUT), U11.8 (FB)
unnamed: C17.1, C18.1, R7.2, U12.1 (AVDD)
unnamed: C16.1, R6.2, U10.1, U12.5 (CH0)
unnamed: C24.2, C25.2, R8.2, U12.20 (DVDD)
unnamed: U12.4 (REFIN+/OUT), U16.1, U16.4 (-)
unnamed: C44.1, R15.2, U16.3 (+)

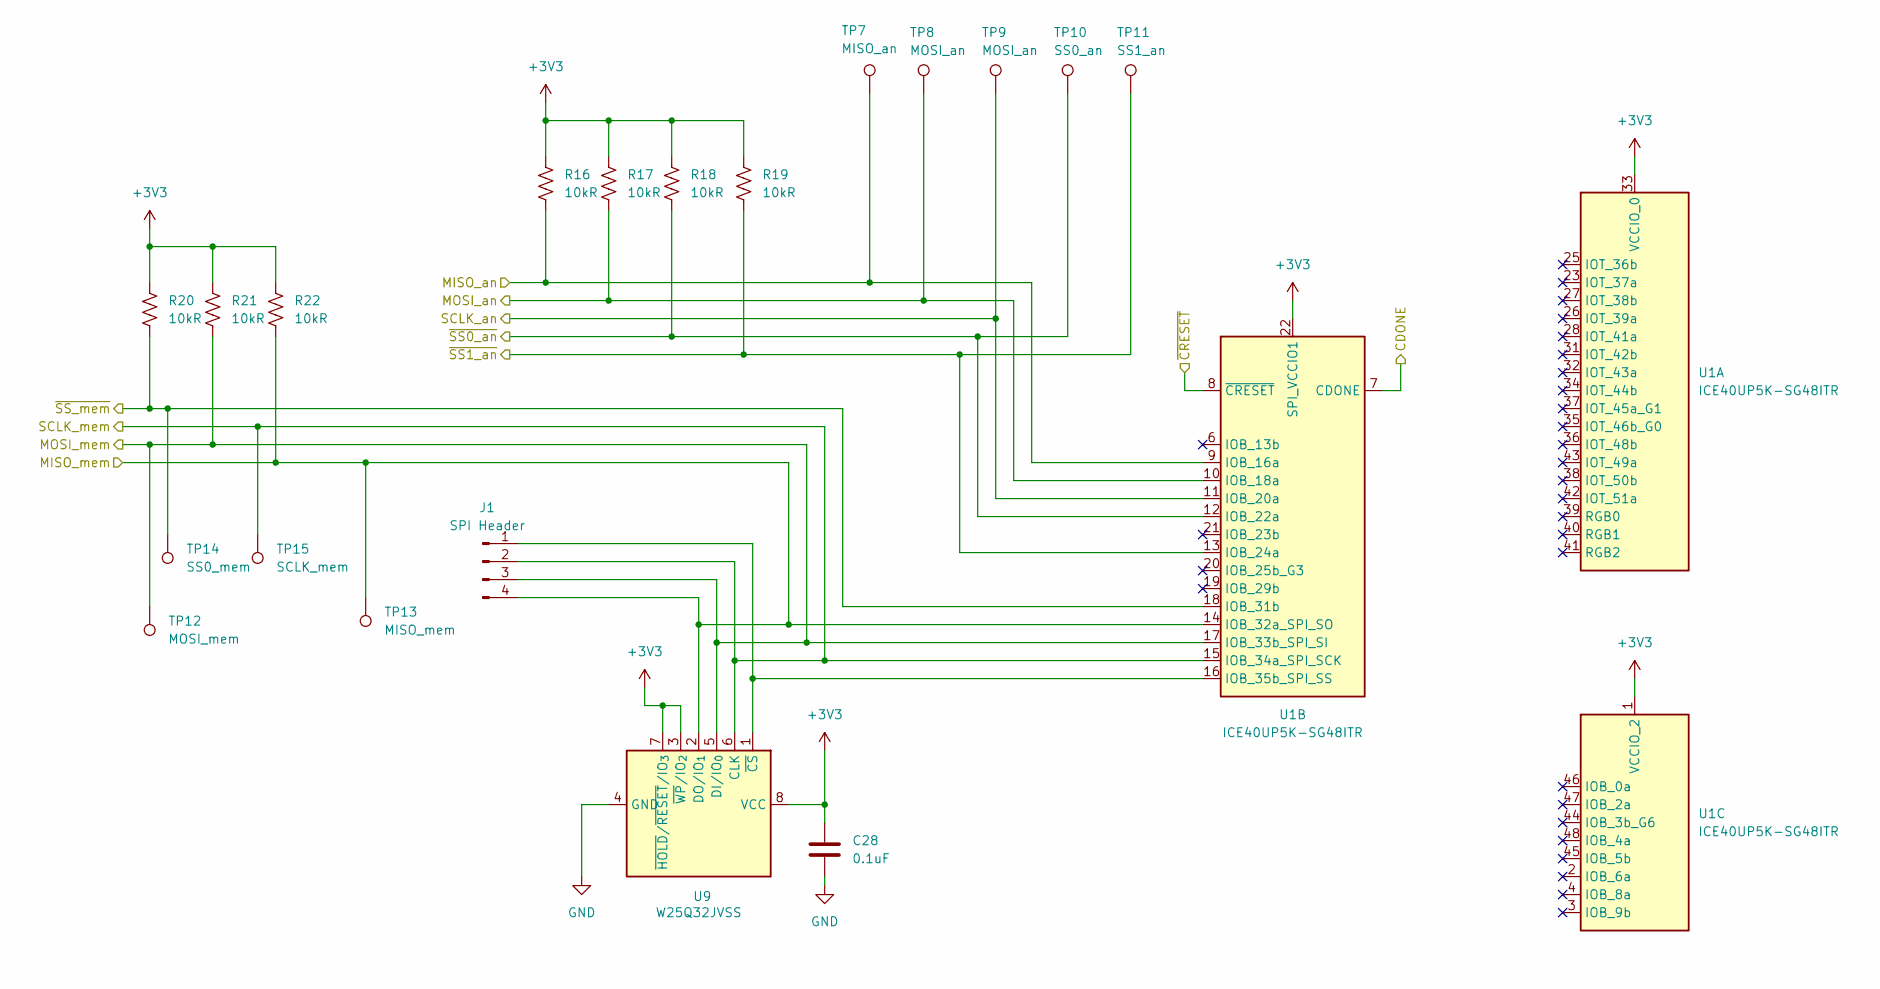
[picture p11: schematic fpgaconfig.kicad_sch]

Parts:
C28: 0.1uF; C_0805_2012Metric_Pad1.18x1.45mm_HandSolder
J1: SPI Header; PinHeader_1x04_P2.54mm_Vertical
R16, R17, R18, R19, R20, R21, R22: 10kR; R_0805_2012Metric_Pad1.20x1.40mm_HandSolder
TP7: MISO_an; TestPoint_Pad_D1.0mm
TP8, TP9: MOSI_an; TestPoint_Pad_D1.0mm
TP10: SS0_an; TestPoint_Pad_D1.0mm
TP11: SS1_an; TestPoint_Pad_D1.0mm
TP12: MOSI_mem; TestPoint_Pad_D1.0mm
TP13: MISO_mem; TestPoint_Pad_D1.0mm
TP14: SS0_mem; TestPoint_Pad_D1.0mm
TP15: SCLK_mem; TestPoint_Pad_D1.0mm
U1: ICE40UP5K-SG48ITR; QFN-48-1EP_7x7mm_P0.5mm_EP5.6x5.6mm
U9: W25Q32JVSS; SOIC-8_5.3x5.3mm_P1.27mm

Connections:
+3V3: C28.1, R16.1, R17.1, R18.1, R19.1, R20.1, R21.1, R22.1, U1.1 (VCCIO_2), U1.22 (SPI_VCCIO1), U1.33 (VCCIO_0), U9.3 (~WP/IO_{2}), U9.7 (~HOLD/~RESET/IO_{3}), U9.8 (VCC); also elsewhere on the board
/CDONE: U1.7 (CDONE); also elsewhere on the board
/MISO_an: R16.2, TP7.1, U1.9 (IOB_16a); also elsewhere on the board
/MISO_mem: J1.4, R22.2, TP13.1, U1.14 (IOB_32a_SPI_SO), U9.2 (DO/IO_{1}); also elsewhere on the board
/MOSI_an: R17.2, TP8.1, U1.10 (IOB_18a); also elsewhere on the board
/MOSI_mem: J1.3, R21.2, TP12.1, U1.17 (IOB_33b_SPI_SI), U9.5 (DI/IO_{0}); also elsewhere on the board
/SCLK_an: TP9.1, U1.11 (IOB_20a); also elsewhere on the board
/SCLK_mem: J1.2, TP15.1, U1.15 (IOB_34a_SPI_SCK), U9.6 (CLK); also elsewhere on the board
/~CRESET: U1.8 (~CRESET); also elsewhere on the board
/~SS0_an: R18.2, TP10.1, U1.12 (IOB_22a); also elsewhere on the board
/~SS0_mem: R20.2, TP14.1, U1.18 (IOB_31b); also elsewhere on the board
/~SS1_an: R19.2, TP11.1, U1.13 (IOB_24a); also elsewhere on the board
GND: C28.2, U9.4 (GND); also elsewhere on the board
unnamed: J1.1, U1.16 (IOB_35b_SPI_SS), U9.1 (~CS)

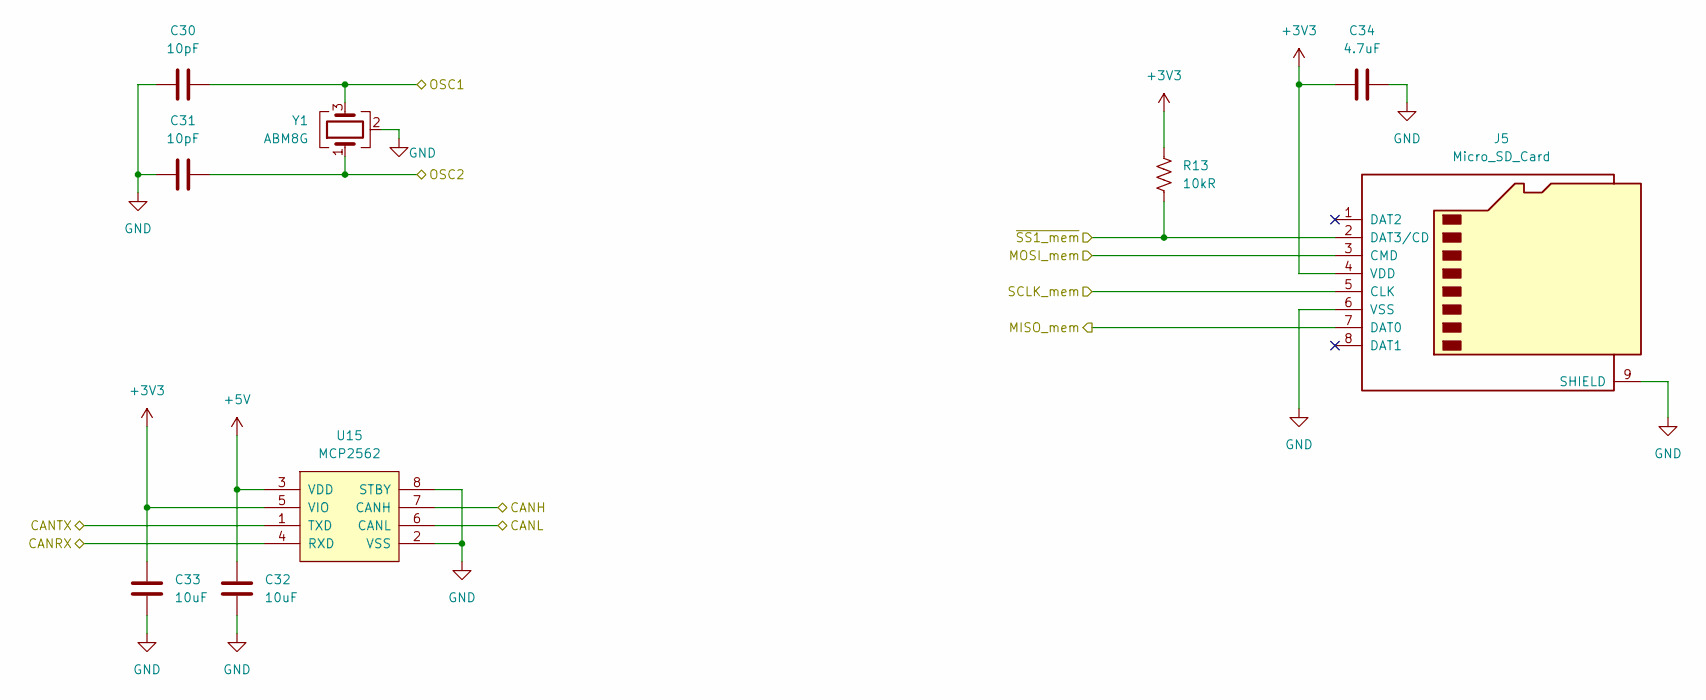
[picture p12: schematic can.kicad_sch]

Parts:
C30, C31: 10pF; C_0805_2012Metric_Pad1.18x1.45mm_HandSolder
C32, C33: 10uF; C_0805_2012Metric_Pad1.18x1.45mm_HandSolder
C34: 4.7uF; C_0805_2012Metric_Pad1.18x1.45mm_HandSolder
J5: Micro_SD_Card; microSD_Molex_WM6698CT-ND
R13: 10kR; R_0805_2012Metric_Pad1.20x1.40mm_HandSolder
U15: MCP2562; SOIC-8_3.9x4.9mm_P1.27mm
Y1: ABM8G; Crystal_SMD_Abracon_ABM8G-4Pin_3.2x2.5mm

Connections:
+3V3: C33.1, C34.2, J5.4 (VDD), R13.1, U15.5 (VIO); also elsewhere on the board
+5V: C32.1, U15.3 (VDD); also elsewhere on the board
/CANH: U15.7 (CANH); also elsewhere on the board
/CANL: U15.6 (CANL); also elsewhere on the board
/CAN_RX: U15.4 (RXD); also elsewhere on the board
/CAN_TX: U15.1 (TXD); also elsewhere on the board
/MISO_mem: J5.7 (DAT0); also elsewhere on the board
/MOSI_mem: J5.3 (CMD); also elsewhere on the board
/OSC1: C30.2, Y1.3; also elsewhere on the board
/OSC2: C31.2, Y1.1; also elsewhere on the board
/SCLK_mem: J5.5 (CLK); also elsewhere on the board
/~SS1_mem: J5.2 (DAT3/CD), R13.2; also elsewhere on the board
GND: C30.1, C31.1, C32.2, C33.2, C34.1, J5.6 (VSS), J5.9 (SHIELD), U15.2 (VSS), U15.8 (STBY), Y1.2 (G), Y1.4 (G); also elsewhere on the board

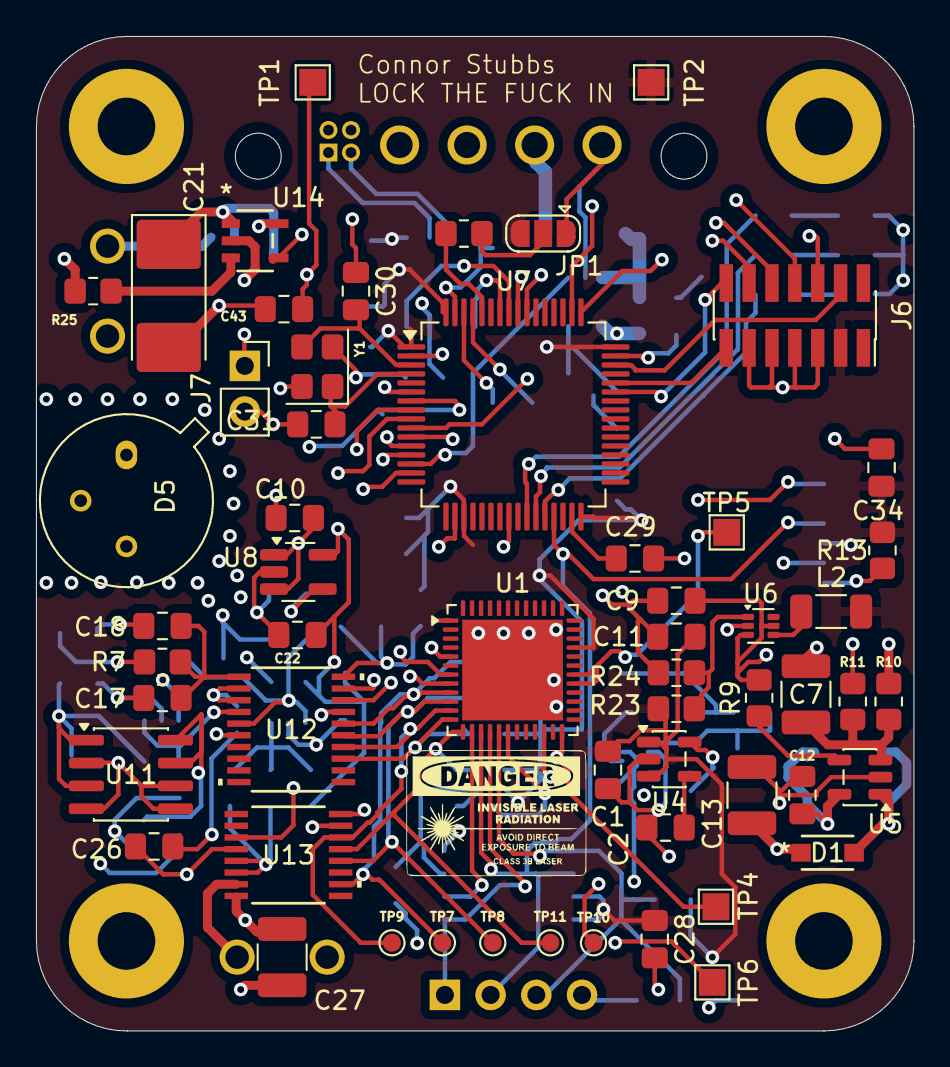
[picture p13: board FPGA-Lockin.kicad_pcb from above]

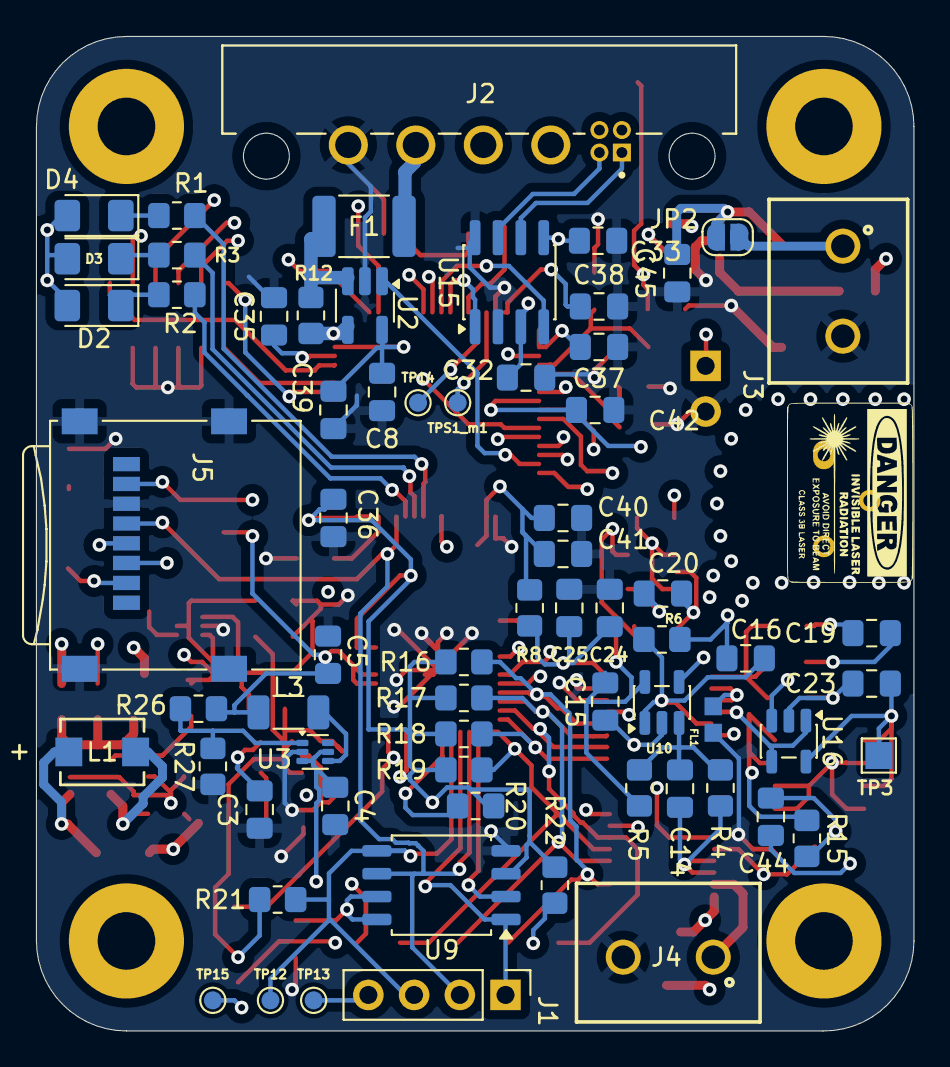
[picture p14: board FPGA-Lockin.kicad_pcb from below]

Board: 4 copper layers, 48.8 x 55.2 mm, 127 parts (67 on the bottom side), 73 nets.

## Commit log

2026-03-04 Fix Pranav review suggestions
    [FPGA-Lockin.kicad_pcb, analog.kicad_sch, power.kicad_sch]
2026-03-10 Fix review suggestions from non-fpga board
    [FPGA-Lockin.kicad_pcb, FPGA-Lockin.kicad_sch, analog.kicad_sch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]
2026-03-12 Fix layout errors after reviewing
    [FPGA-Lockin.kicad_pcb, power.kicad_sch]
2026-03-12 Fix diode
    [BLM18PG121SN1D.step, FPGA-Lockin.kicad_pcb, FPGA-Lockin.kicad_sch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]
2026-03-16 Fix everything based on component availabilty
    [FPGA-Lockin-B_Cu.gbr, FPGA-Lockin-B_Mask.gbr, FPGA-Lockin-B_Silkscreen.gbr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]
